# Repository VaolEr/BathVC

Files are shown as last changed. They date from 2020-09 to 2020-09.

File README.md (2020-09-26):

# BathVC-Project
Bathroom ventilator controller project.

This project is for informational purposes only. If you decide to repeat this device, the author is not responsible for problems that occur when trying to repeat them. If you decide to repeat it and You have any questions - feel free to ask them, I will be happy to answer in my free time!

This project was designed to control the exhaust fan in my bathroom.

The main task is to start the fan when the humidity level is exceeded, which is set in the app on your phone.
At the same time, information about the humidity level, temperature, and fan status (on or off) is transmitted to the phone.

A fan is a device that operates on a 220V 50-60Hz network.
Since it is necessary to switch a high-voltage device, I developed a printed circuit Board for this purpose, 
which implements a high-voltage load control scheme by switching a relay.

The ESP8266 NodeMCU Board was chosen as the MAIN device, because it is WiFI MCU with enouth free pins for this task.
SHT31-d is selected as the humidity sensor.
The user interface is designed on Blink, due to the simplicity of organizing communication between the NodeMCU card and the phone.
Also for power on/off device I use SensorButton from Aliexpress, link below
https://aliexpress.ru/item/32788526867.html?spm=a2g0s.9042311.0.0.264d33edvKP69V

In folder pcbGerbers You can find pcb gerber files and bill of materials. 
//--------------------------------------------------------------------------------------------------------------------------//

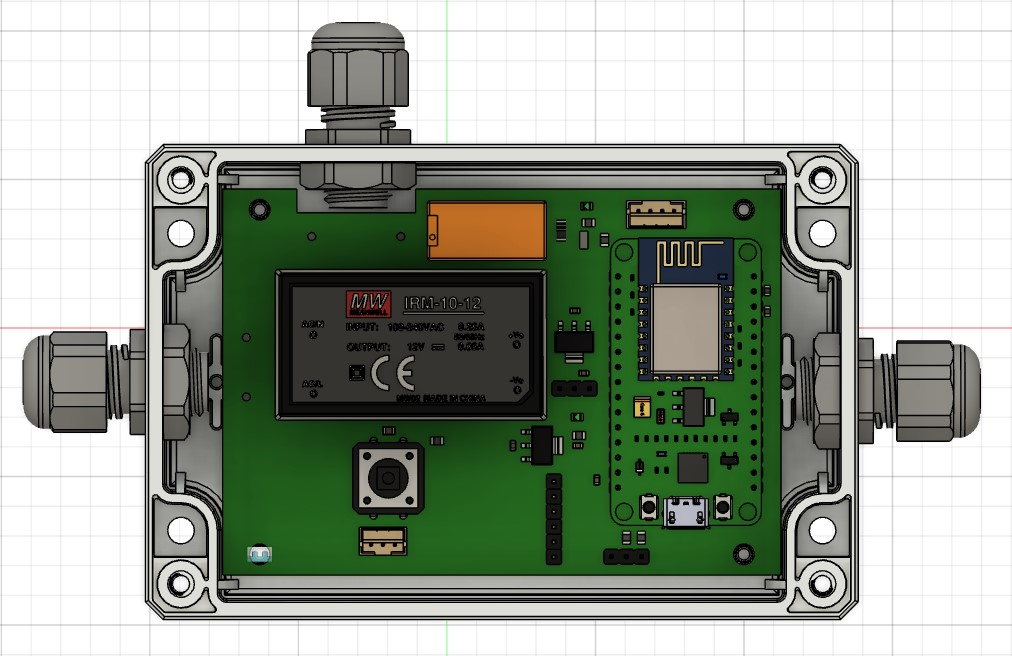
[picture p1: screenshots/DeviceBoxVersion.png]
Autodec360 device model view 1

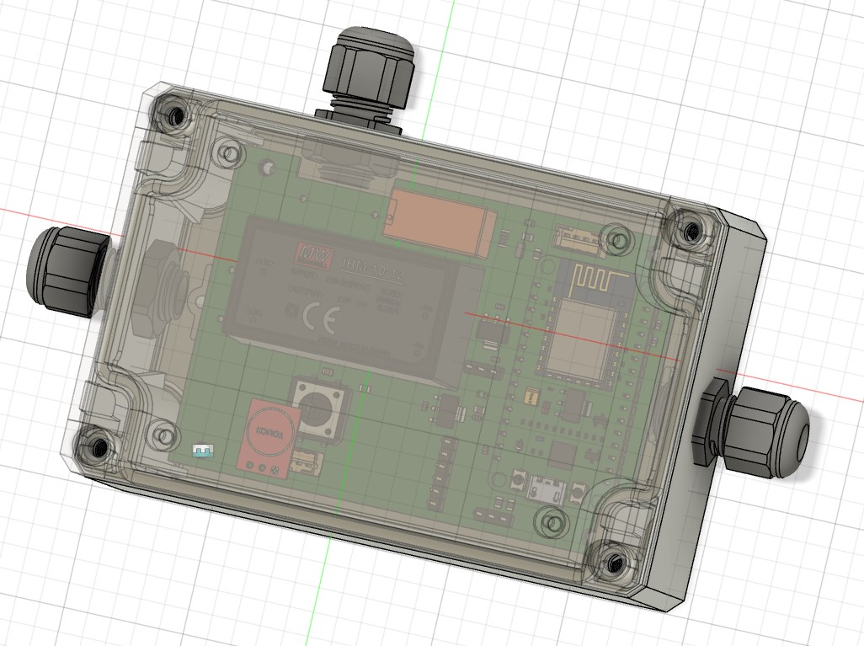
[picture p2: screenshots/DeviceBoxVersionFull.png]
Autodec360 device model view 2

 
 //--------------------------------------------------------------------------------------------------------------------------//

 Lower I want to show PCB boards models. There was designed 2 versions: one was clemmas, and one with soldering pads for connect AC and Load 
 with device.

//--------------------------------------------------------------------------------------------------------------------------//

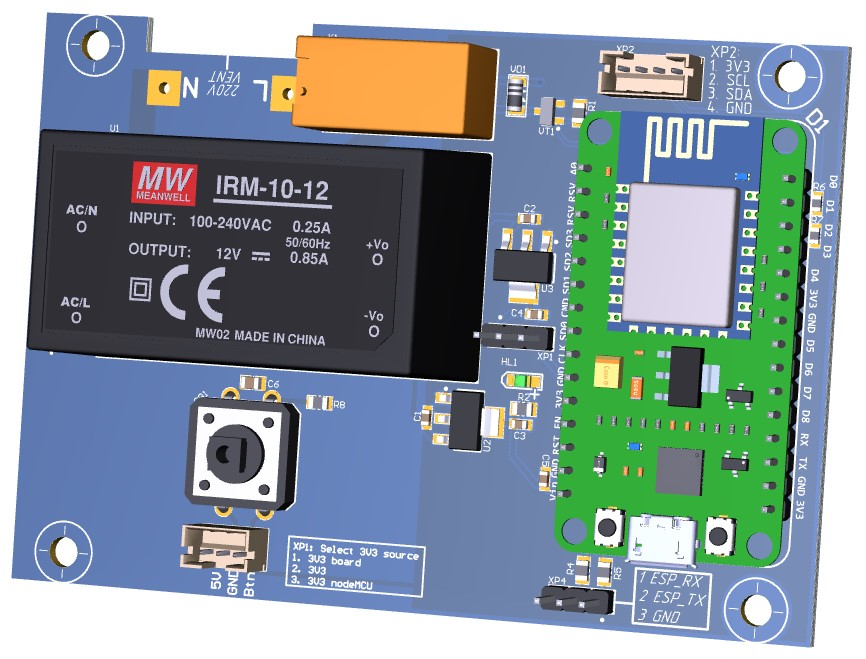
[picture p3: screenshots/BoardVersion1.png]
Board version for soldering

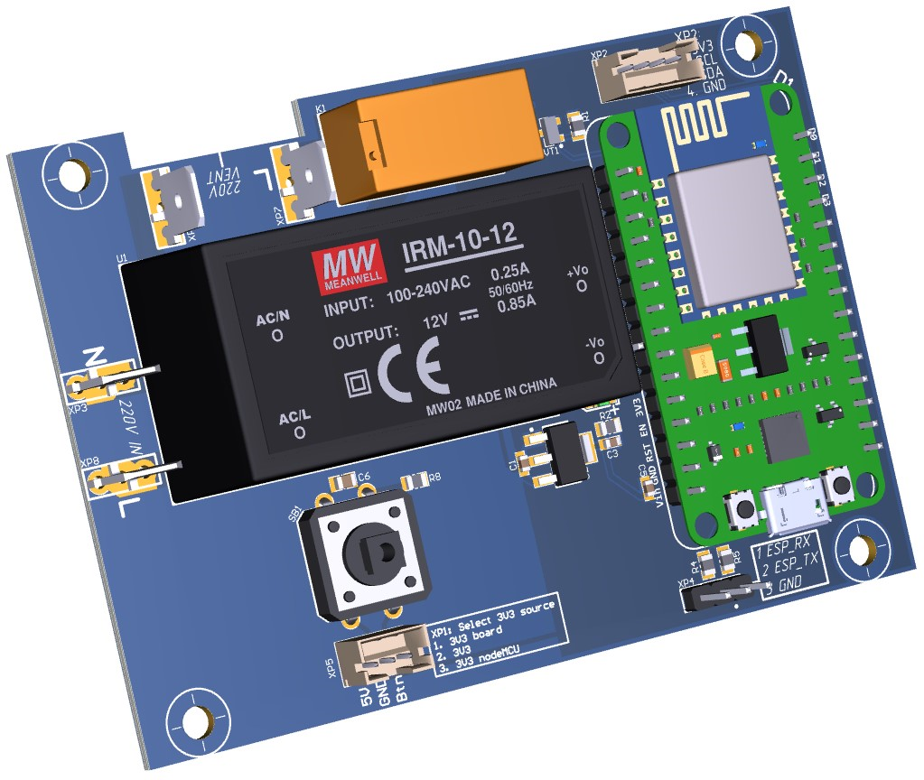
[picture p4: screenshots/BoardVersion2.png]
Board version with clemmas


//--------------------------------------------------------------------------------------------------------------------------//

Work example of Blynk APP show below.

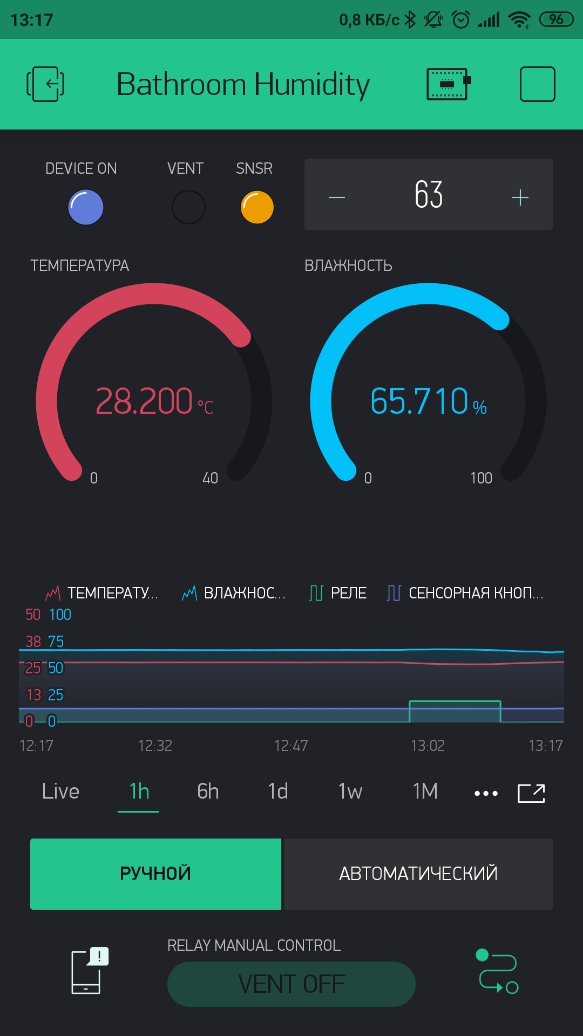
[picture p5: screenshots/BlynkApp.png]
Blynk APP


The ESP8266 firmware and Arduino IDE settings are located in the firmware folder.
In the folder there are 2 pcb3dViews PDF file to view the versions of boards in 3D.

//--------------------------------------------------------------------------------------------------------------------------//
Данный проект носит ознакомительный характер. Если же вы решите повторить данное устройство, то автор не несёт ответственности за проблемы, возникшие при попытках их повторить. Если же Вы решитесь его повторить и у Вас появятся вопросы - смело их задавайте, отвечу с радостью в свободное время!

Данный проект был разработан для упралвения вытяжным вентилятором в моей ванной.

Основная задача - запускать вентилятор при превышении уровня влажности, который задаётся в приложении на телефоне.
В то же время на телефон передаётся информация об уровне влажности, температуре и состоянии вентилятора (включен и выключен).

Вентилятор - устроство, работающее от сети 220В 50-60Hz.

Поскольку необходимо коммутировать высоковольтное устройство, то для этих целей мной была разработана печатная плата, 
на которой реализована схема управления высоковольтной нагрузкой посредством коммутации реле.  

В качестве основного устройства была выбрана плата ESP8266 в исполнении NodeMCU, так как поддерживает работу по WiFI и обладает
достаточным количеством свободных пинов для решения поставленной задачи.
В качестве датчика влажности выбран SHT31-D.
Интерфейс пользователя разработан на Blynk, ввиду простоты организации связи между платой NodeMCU и телефоном.
Так же для включения устройства я использую сенсорную кнопку с Aliexpress, ссылка на которую указана ниже
https://aliexpress.ru/item/32788526867.html?spm=a2g0s.9042311.0.0.264d33edvKP69V

Прошивка ESP8266 и настройки ArduinoIDE расположены в папке firmware.
В папке pcb3dViews находятся 2 PDF файла для просмотра версий плат в 3D.

В папке pcbGerbers вы можете найти pcb gerber files and перечень используемых элементов.

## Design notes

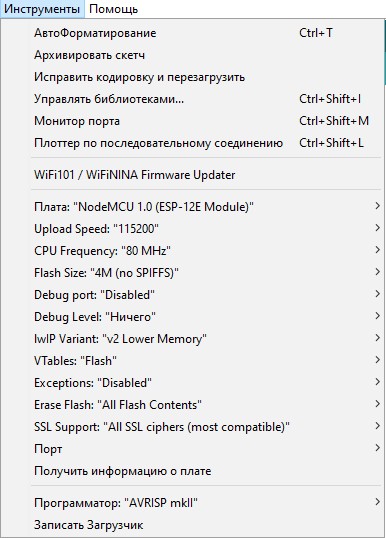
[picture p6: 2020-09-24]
firmware/ArduinoIDE-settings/Instruments.jpg

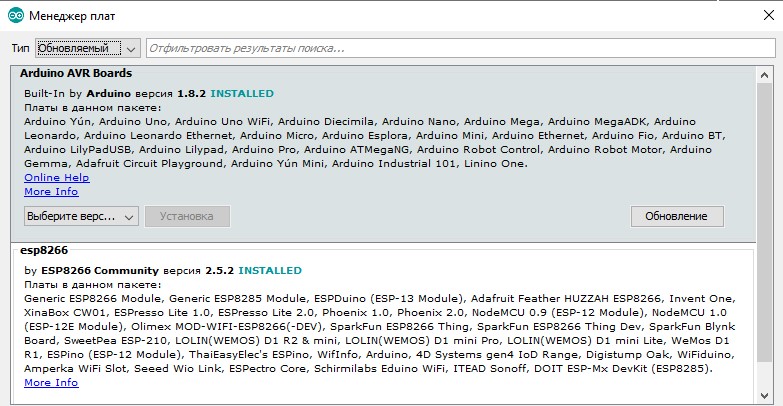
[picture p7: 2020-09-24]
firmware/ArduinoIDE-settings/Boards manager.jpg

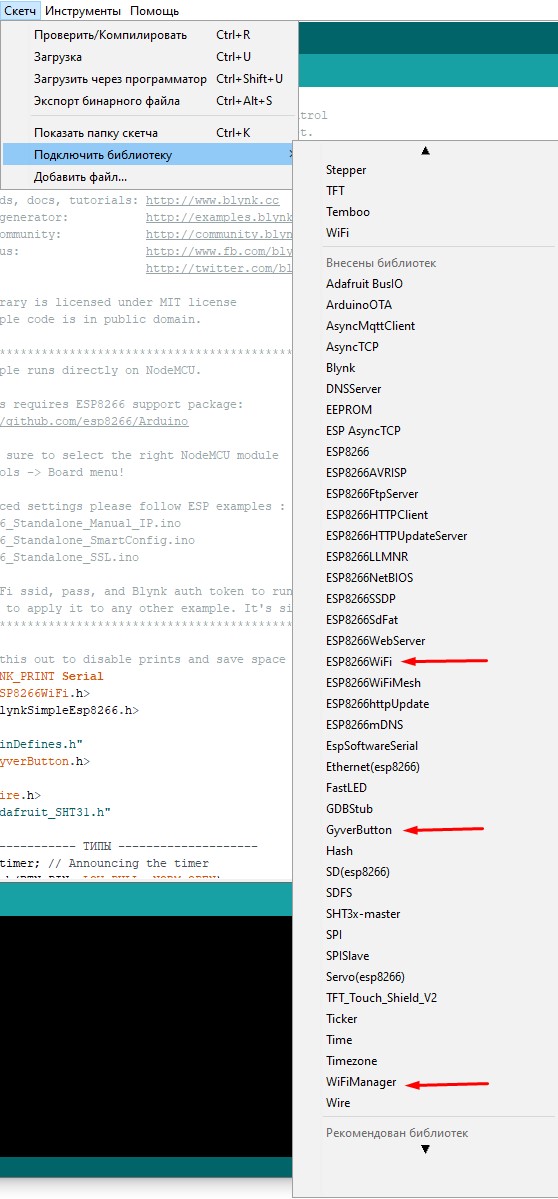
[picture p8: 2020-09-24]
firmware/ArduinoIDE-settings/Libs.jpg

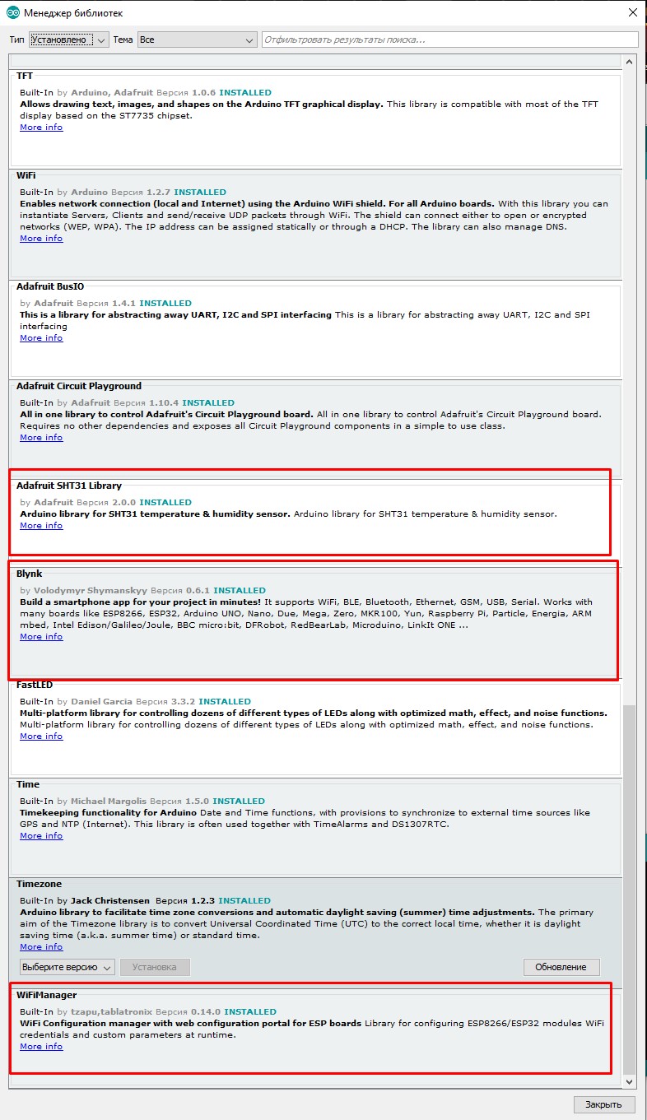
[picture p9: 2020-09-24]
firmware/ArduinoIDE-settings/Libs manager.jpg

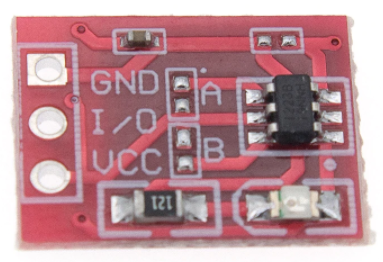
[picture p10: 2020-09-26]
screenshots/SensorButtonForDevice.png

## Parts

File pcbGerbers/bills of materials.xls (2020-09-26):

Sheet: BOM Report
Bill of Materials |  |  | Bill of Materials for Schematic Document [BHC.SchDoc]
Source Data From: |  | BHC.SchDoc
Project: |  | BHC.PrjPcb
Variant: |  | None
Creation Date: | 26.09.2020 | 13:38
Print Date: | 2020-09-26 | 13:39:48
Footprint | Comment | LibRef | Designator | Description | Quantity
CAPC1608X85N | 0,1мк | C0603X104K5RAC7411 | C1 | Керамический конденсатор 0,1мкФ X7R 50В 10% 0603-GRM188R71H104K | 1
CAPC1608X85N | 0,1мк | C0603X104K5RAC7411 | C2 | Керамический конденсатор 0,1мкФ X7R 50В 10% 0603-GRM188R71H104K | 1
CAPC1608X85N | 10мк | GRM188R61E106KA73D | C3 | Керамический конденсатор 10 мкФ X5R 25В 10% 0603-GRM188R61E106KA73D Murata | 1
CAPC1608X85N | 10мк | GRM188R61E106KA73D | C4 | Керамический конденсатор 10 мкФ X5R 25В 10% 0603-GRM188R61E106KA73D Murata | 1
CAPC1608X85N | 0,1мк | C0603X104K5RAC7411 | C5 | Керамический конденсатор 0,1мкФ X7R 50В 10% 0603-GRM188R71H104K | 1
CAPC2012X110N | 0,1мк | GCD21BR71H104KA01L | C6 | Керамический конденсатор 0,1 мкФ X7R 50В 10% 0805-GRM21BR71H104KA01K | 1
nodeMCU_AMICA |  | nodeMCU_AMICA | D1 | nodeMCU AMICA | 1
LED2012 |  | BL-LS0805UYC | HL1 | Светодиод 0805 BL-LS0805UYC Betlux Electronics "Betlux Electronics" | 1
SCHRACK-RE-series | SCHRACK-RE-series | RE030012 | K1 | 1393217-4 (RE030012 PBF), Реле 12VDC 1зам. 6A/250VAC | 1
RESC2012X60N | 10к | RC0805FR-0710KL | R1 | Резистор плёночный 10 кОм 0.125Вт 1% 0805-RC0805FR-0710KL Yageo | 1
RESC2012X60N | 300 | RC0805JR-07300RL | R2 | Резистор плёночный 300 Ом 0.125Вт 5% 0805-RC0805JR-07300RL Yageo | 1
RESC2012X60N | 100 | RC0805FR-07100RL | R4 | Резистор плёночный 100 Ом 0.125Вт 1% 0805-RC0805FR-07100RL Yageo | 1
RESC2012X60N | 100 | RC0805FR-07100RL | R5 | Резистор плёночный 100 Ом 0.125Вт 1% 0805-RC0805FR-07100RL Yageo | 1
RESC1608X55N | 1.5к | RC0603FR-071K5L | R6 | Резистор плёночный 1.5 кОм 0.1Вт 1% 0603-RC0603FR-071K5L Yageo | 1
RESC1608X55N | 1.5к | RC0603FR-071K5L | R7 | Резистор плёночный 1.5 кОм 0.1Вт 1% 0603-RC0603FR-071K5L Yageo | 1
RESC2012X60N | 150к | RC0805FR-07150KL | R8 | Резистор плёночный 150 кОм 0.125Вт 1% 0805-RC0805FR-07150KL Yageo | 1
FSM103A |  | FSM103A | SB1 | Кнопка тактовая h=7.3 мм SPST | 1
IRM-10 | AC220-DC12 | IRM-10-12 | U1 | AC-DC преобразователь, 10ВТ вход 220 выход 12, MEAN Well | 1
SOT-223 | LD1117 | LD1117S50CTR | U2 | LDO регуляторы напряжения 5.0V 0.8A Positive 15V Input | 1
SOT-223 | LD1117 | AMS1117-3.3 | U3 | LDO регуляторы напряжения 3.3V 0.8A Positive 15V Input | 1
SOD80C |  | BZV55-B12.115 | VD1 | Стабилитрон / Диод Зенера BZV55-B12.115 | 1
3-Lead SOT23 |  | 2N7002 | VT1 | 60V, 300mA, N-channel Trench MOSFET | 1
PLS-3 |  | DS1021-1*3SF11-B | XP1 | Вилка прямая штыревая 2.54мм 1х3 тип1 PLS-3 (DS1021-1*3) Connfly Electronics | 1
B4B-PH-K-S |  | B4B-PH-K-S | XP2 | Вилка прямая штыревая 2мм 1х4 тип B4B-PH-K-S | 1
63824-1 |  | 63824-1 | XP3 | Клемма на печатную плату, 6.35мм x 0.81мм, 0.25" x 0.032", Латунь, 1.4 мм, Олово, FASTON 250 Series | 1
PLS-3 |  | DS1021-1*3SF11-B | XP4 | Вилка прямая штыревая 2.54мм 1х3 тип1 PLS-3 (DS1021-1*3) Connfly Electronics | 1
B3B-PH-K-S |  | B3B-PH-K-S | XP5 | Вилка прямая штыревая 2мм 1х3 тип B3B-PH-K-S | 1
63824-1 |  | 63824-1 | XP6 | Клемма на печатную плату, 6.35мм x 0.81мм, 0.25" x 0.032", Латунь, 1.4 мм, Олово, FASTON 250 Series | 1
63824-1 |  | 63824-1 | XP7 | Клемма на печатную плату, 6.35мм x 0.81мм, 0.25" x 0.032", Латунь, 1.4 мм, Олово, FASTON 250 Series | 1
63824-1 |  | 63824-1 | XP8 | Клемма на печатную плату, 6.35мм x 0.81мм, 0.25" x 0.032", Латунь, 1.4 мм, Олово, FASTON 250 Series | 1
 |  |  |  |  | 30
Approved |  | Notes
 |  | For BHC-V2 version you don't need 63824-1

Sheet: Project Information
Project Full Path | E:\Work\Work\Eureca\PCBs\VEStriXProjects\BathHumidityControl\BHC.PrjPcb
Project Filename | BHC.PrjPcb
Variant Name | None
Data-Source Filename | BHC.SchDoc
Data-Source Full Path | E:\Work\Work\Eureca\PCBs\VEStriXProjects\BathHumidityControl\BHC.SchDoc
Title | Bill of Materials for Schematic Document [BHC.SchDoc]
Total Quantity | 30
Report Time | 13:38
Report Date | 26.09.2020
Report Date & Tine | 26.09.2020 13:38
Output Name | Bill of Materials
Output Type | BOM_PartType
Output Generator Name | BOM
Output Generator Description | Bill of Materials

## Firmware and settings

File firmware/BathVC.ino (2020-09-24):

/*************************************************************
  Download latest Blynk library here:
    https://github.com/blynkkk/blynk-library/releases/latest

  Blynk is a platform with iOS and Android apps to control
  Arduino, Raspberry Pi and the likes over the Internet.
  You can easily build graphic interfaces for all your
  projects by simply dragging and dropping widgets.

    Downloads, docs, tutorials: http://www.blynk.cc
    Sketch generator:           http://examples.blynk.cc
    Blynk community:            http://community.blynk.cc
    Follow us:                  http://www.fb.com/blynkapp
                                http://twitter.com/blynk_app

  Blynk library is licensed under MIT license
  This example code is in public domain.

 *************************************************************
  This example runs directly on NodeMCU.

  Note: This requires ESP8266 support package:
    https://github.com/esp8266/Arduino

  Please be sure to select the right NodeMCU module
  in the Tools -> Board menu!

  For advanced settings please follow ESP examples :
   - ESP8266_Standalone_Manual_IP.ino
   - ESP8266_Standalone_SmartConfig.ino
   - ESP8266_Standalone_SSL.ino

  Change WiFi ssid, pass, and Blynk auth token to run :)
  Feel free to apply it to any other example. It's simple!
 *************************************************************/

/* Comment this out to disable prints and save space */
#define BLYNK_PRINT Serial
#include <ESP8266WiFi.h>
#include <BlynkSimpleEsp8266.h>

#include "PinDefines.h"
#include <GyverButton.h>

#include <Wire.h>
#include "Adafruit_SHT31.h"

// ------------------- ТИПЫ --------------------
BlynkTimer timer; // Announcing the timer
GButton touch(BTN_PIN, LOW_PULL, NORM_OPEN);

// ----------------- ПЕРЕМЕННЫЕ ------------------
// ----- Режим управления вентилятором
byte Control_Mode; // 1 - Ручной, 2 - Автоматический

// -------- КНОПКА BLYNK --------
bool bButtonOldState;
int  iButtonOldState = 3;

bool bButtonState;
int  iButtonState = 0; // 0 - Вентилятор выключен, 10 - вентилятор включен

// -------- Датчик SHT31-DIS-B -------
Adafruit_SHT31 sht31 = Adafruit_SHT31();
bool sensorState = false;

// -------- ВЛАЖНОСТЬ -------
int ustavka_Humidity = 30;  // Порог срабатывания реле включения вентилятора, %
float Humidity = 60;          // Текущее значение влажности, полученное от датчика, %

// -------- ТЕМПЕРАТУРА -------
float Temperature = 60;       // Текущее значение температуры, полученное от датчика, С

// -------- КНОПКА -------
#define USE_BUTTON 1    // 1 - использовать кнопку, 0 - нет
bool TouchButtonOn = false;


// ----------------- Настрйоки WiFi ------------------
// You should get Auth Token in the Blynk App.
// Go to the Project Settings (nut icon).
char auth[] = "Insert Yor Token";

// Your WiFi credentials.
// Set password to "" for open networks.
char ssid[] = "Your SSID";
char pass[] = "Your Pass";



int i = 0;
void myTimerEvent()
{
  checkSHT31connection();
  myI2C_Humidity_request();
  myHumidityControl();
  //if(i < 40) i++;
  //else i = 0; 
  Blynk.virtualWrite(Blynk_Temperature, Temperature);
  
  Blynk.virtualWrite(Blynk_Humidity, Humidity);

  Blynk.virtualWrite(Blynk_Manual_Vent_OnOff, iButtonState);
}

void myI2C_Humidity_request()
{
  /*Wire.requestFrom(8, 1); /* запрашиваем и считываем данные с 8 адреса slave устройства 1 байта
  while(Wire.available())
  {
    Serial.println("Wire available"); 
    Humidity = Wire.read();
  }
  Serial.println(Humidity);*/
  if(sensorState){ 
    Temperature = sht31.readTemperature();
    Humidity = sht31.readHumidity();
  
    if (! isnan(Temperature)) {  // check if 'is not a number'
      Serial.print("Temp *C = "); Serial.print(Temperature); Serial.print("\t\t");
    } else { 
      Serial.println("Failed to read temperature");
      Temperature = 111;
    }
    
    if (! isnan(Humidity)) {  // check if 'is not a number'
      Serial.print("Hum. % = "); Serial.println(Humidity);
    } else { 
      Serial.println("Failed to read humidity");
      Humidity = 111;
    }
  }
  else{
    Temperature = 222;
    Humidity = 222;
  }
}

void myHumidityControl()
{ 
    if(TouchButtonOn == true)
    { 
      Blynk.virtualWrite(Blynk_Touch_Indicator, 255);
      
      if(Control_Mode == ManualControlMode)
      {

      }
  
      if(Control_Mode == AutomaticControlMode)
      {
        if(Humidity >= ustavka_Humidity)
        {
          iButtonState = 10;
          digitalWrite(Vent_Relay, true);
          Blynk.virtualWrite(Blynk_Vent_ON_LED, 255);  
        }
  
        if(Humidity < ustavka_Humidity)
        {
          iButtonState = 0;
          digitalWrite(Vent_Relay, false);
          Blynk.virtualWrite(Blynk_Vent_ON_LED, 0);
        }
      }
    }
    if(TouchButtonOn == false)
    {
      digitalWrite(Vent_Relay, false);
      Blynk.virtualWrite(Blynk_Vent_ON_LED, 0);
      iButtonState = 0;
      Blynk.virtualWrite(Blynk_Touch_Indicator, 0);
    }
}

void buttonTick()
{
  touch.tick();
  if(USE_BUTTON)
  {
    if (touch.isSingle()) 
    {
      TouchButtonOn = !TouchButtonOn; 
    }
  }
  else
  {
    TouchButtonOn = true;
  }
}

void checkSHT31connection(){
  Serial.println("SHT31 test");
  sensorState = true;
  Blynk.virtualWrite(Blynk_SHT31_LED, 255);
  if (! sht31.begin(0x44)) {   // Set to 0x45 for alternate i2c addr
    Serial.println("Couldn't find SHT31");
    sensorState = false;
    Blynk.virtualWrite(Blynk_SHT31_LED, 0);
    while (1) delay(1);
  }
}

void setup()
{
  //Wire.begin(D2,D1);
  
  pinMode(BTN_PIN, INPUT);
  touch.setStepTimeout(100);
  touch.setClickTimeout(500);
  
  // Debug console
  Serial.begin(115200);

  //Blynk.begin(auth, ssid, pass);
  // You can also specify server:
  //Blynk.begin(auth, ssid, pass, "blynk-cloud.com", 80);
  
  Blynk.begin(auth, ssid, pass, IPAddress(139,59,206,133), 8080); // Connect to Blynk Server

  timer.setInterval(4000L, myTimerEvent);
  
  pinMode(Vent_Relay, OUTPUT);      //Set the Relay Control pin mode to output
  digitalWrite(Vent_Relay, false);  //Set the Relay Control pin lvl to LOW

  Control_Mode = ManualControlMode;
  Blynk.virtualWrite(Blynk_Control_Mode, ManualControlMode);
  Blynk.setProperty(Blynk_Control_Mode, "color", "#23C48E");
}

BLYNK_WRITE(Blynk_Control_Mode)
{
  Control_Mode = param.asInt();
  switch (Control_Mode){
    case ManualControlMode:{
      Blynk.setProperty(Blynk_Control_Mode, "color", "#23C48E");
      Blynk.setProperty(Blynk_Manual_Vent_OnOff, "onBackColor", "#23C48E");
      Blynk.setProperty(Blynk_Manual_Vent_OnOff, "offBackColor", "#1F473D");}
    break;
    case AutomaticControlMode:{
      Blynk.setProperty(Blynk_Control_Mode, "color", "#04C0F8");
      Blynk.setProperty(Blynk_Manual_Vent_OnOff, "onBackColor", "#2C2D31");
      Blynk.setProperty(Blynk_Manual_Vent_OnOff, "onColor", "#17181B");
      Blynk.setProperty(Blynk_Manual_Vent_OnOff, "offColor", "#17181B");
      Blynk.setProperty(Blynk_Manual_Vent_OnOff, "offBackColor", "#2C2D31");}
    break;
  }
  myHumidityControl();
}

BLYNK_WRITE(Blynk_Manual_Vent_OnOff)   
{
  if(TouchButtonOn)
  {
    iButtonOldState = iButtonState;
  
    if(Control_Mode == ManualControlMode)
    { 
      iButtonState = param.asInt(); // read value from virtual pin
      if(iButtonState == 10) 
      {
        Blynk.virtualWrite(Blynk_Vent_ON_LED, 255);
        digitalWrite(Vent_Relay, true);
      }
      if(iButtonState == 0)
      {
        Blynk.virtualWrite(Blynk_Vent_ON_LED, 0);
        digitalWrite(Vent_Relay, false);
      }
    }
    if(Control_Mode == AutomaticControlMode)
    {
      Blynk.notify(String("Для независимого управления вентилятором смените режим на Ручной."));
      Blynk.virtualWrite(Blynk_Manual_Vent_OnOff, iButtonState);
    }
  }
  else
  {
    Blynk.notify(String("Включите работу устройства одиночным нажатием кнопки на корпусе устройства."));
  }
}

BLYNK_WRITE(Blynk_Humidity_Ustavka)
{
    ustavka_Humidity = param.asInt();
    //myHumidityControl();
}

void loop()
{
  Blynk.run();
  timer.run();
  buttonTick();
}

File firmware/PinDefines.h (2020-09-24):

// ESP8266 pins defines //
#define Vent_Relay  D0
//------------------//
#define I2C_SCL     D1
#define I2C_SDA     D2
#define I2C_addr    8
//------------------//
#define BTN_PIN     D8
//------------------//
#define SPI_SCK     D5
#define SPI_MISO    D6
#define SPI_MOSI    D7
#define SPI_CS      D8
//------------------//

// Blynk Virtual Pins defines //
#define Blynk_Control_Mode      V3 // Select the Control Mode ( Manual or Automatic )
#define Blynk_Temperature       V6 // Temperature Gauge value
#define Blynk_Humidity          V5 // Humidity Gauge value
#define Blynk_Vent_ON_LED       V0 // Ventilator ON OFF LED value
#define Blynk_SHT31_LED         V4 // SHT31 sensor status LED value
#define Blynk_Humidity_Ustavka  V2 // Humidity on/off ventilation ustavka
#define Blynk_Manual_Vent_OnOff V1 // Manual ventilator relay control
#define Blynk_Touch_Indicator	 V10 // Manual ventilator relay control

#define ManualControlMode 1
#define AutomaticControlMode 2

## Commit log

2020-09-26 ESP8266 firmware was placed in firmware folder. Added PCBs screenshots, pcb3D Views and updated README.md file.
2020-09-26 Add bills of materials and gerber files.
    [BHC_V2.DRL, BHC_V2.GBL, BHC_V2.GBO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]
